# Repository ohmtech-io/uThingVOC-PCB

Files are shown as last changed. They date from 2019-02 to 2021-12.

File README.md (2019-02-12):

# uThing::VOC Hardware
### Air-Quality sensor USB dongle with configurable output format

#### Schematic and PCB manufacturing files for the uThing::VOC

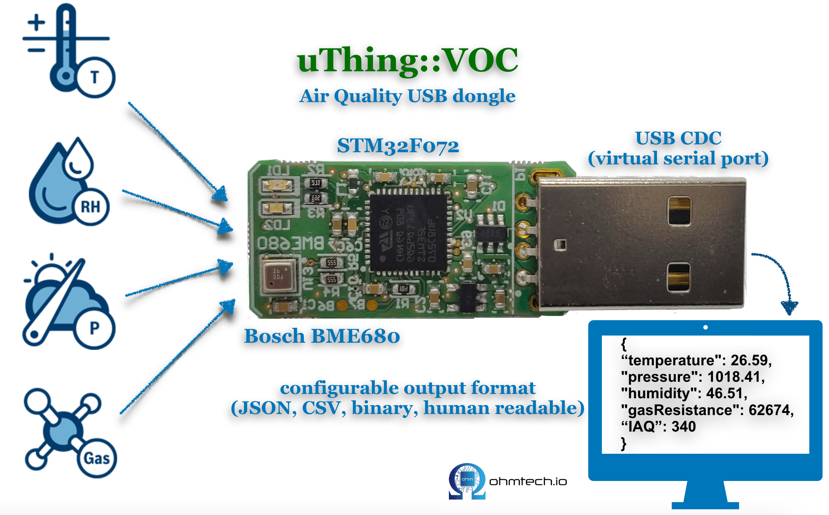
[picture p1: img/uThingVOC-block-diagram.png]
uThingVOC


This repository contains the design files for the revision.1 of the OhmTech's uThing::VOC USB dongle.

The PCB is layered out in a 4-layer FR4 board.

Below is a list of the requirements for the fabrication technology:

* Number of Layers: 4
* Total board thickness: 1.55 mm
* Legend (silkscreen): White. Top and Bottom
* Base material: FR4
* Smallest via: >= 0.25 mm
* Outer layer isolation distance ﴾OL‐TT‐TP‐PP: 0.150 mm (6 mil)
* Outer layer track-width ﴾IL‐TW﴿: 0.150 mm (6 mil)
* Inner layer isolation distance ﴾IL‐TT‐TP‐PP: 0.150 mm (6 mil)
* Inner layer track-width ﴾IL‐TW﴿: 0.150 mm (6 mil)
* Board buildup: Standard, no special requirement
* Inner layer copper foil: 35 um
* Outer layer copper foil: 18 um
* Surface finish: any lead-free finish

The PCB Outer dimensions are 30x14.5 mm, with the USB-A connector installed the final dimension is approx. 48x15x5 mm.

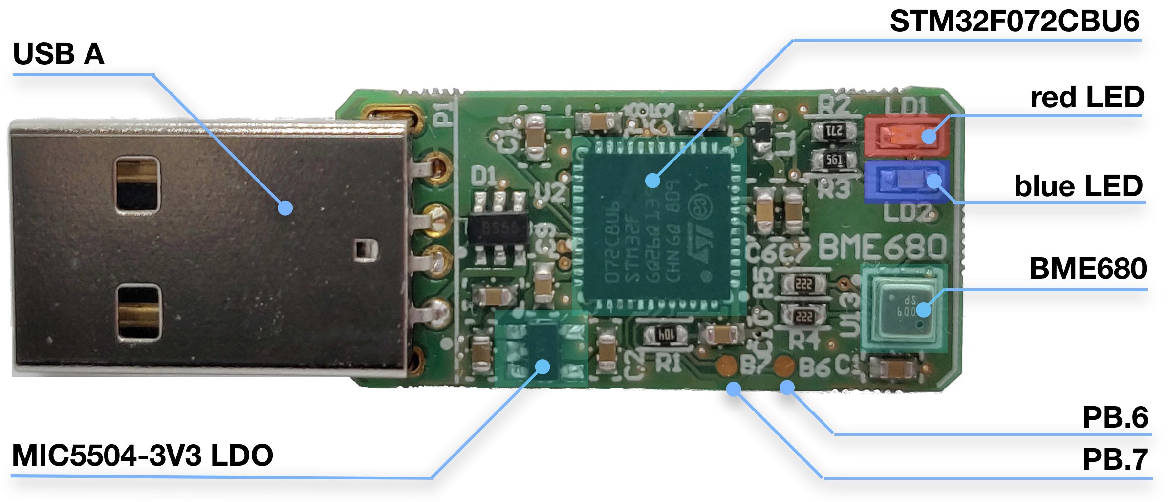
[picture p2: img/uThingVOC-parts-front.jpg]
uThingVOCfront

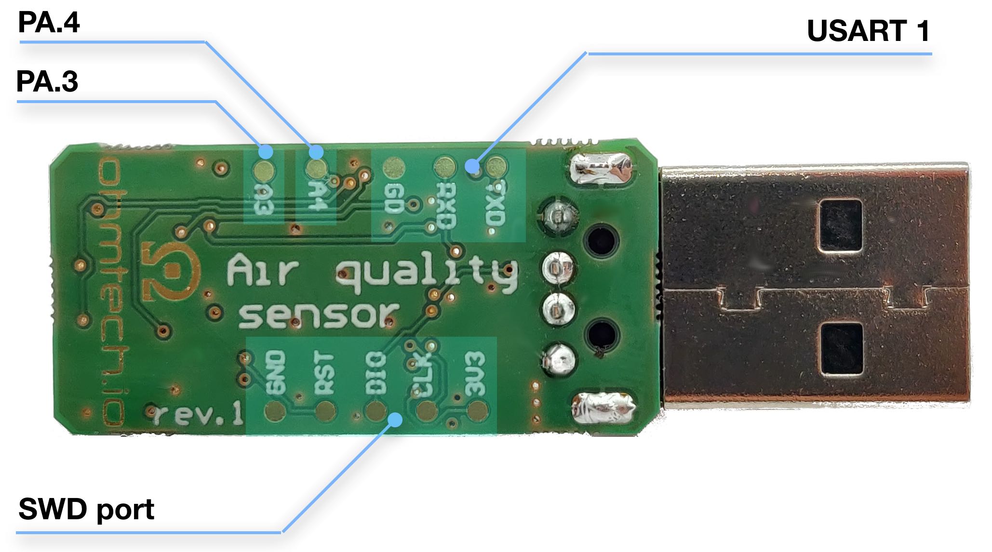
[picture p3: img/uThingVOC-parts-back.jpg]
uThingVOCback


Gerber BOM and Pick&Place files are provided for PCB manufacturing and assembly.

* The Firmware source code can be found here: https://github.com/ohmtech-io/uThingVOC.git
* The assembled boards can be obtained at the Tindie store: https://www.tindie.com/products/damancuso/uthingvoc/

If you like the project please share and follow us on [Tweeter](https://twitter.com/OhmTechIot) :)

------------------

**License**

**Copyright (c) 2019 Daniel Mancuso - OhmTech.io**

<br />This work is licensed under a <a rel="license" href="http://creativecommons.org/licenses/by-sa/4.0/">Creative Commons Attribution-ShareAlike 4.0 International License</a>.

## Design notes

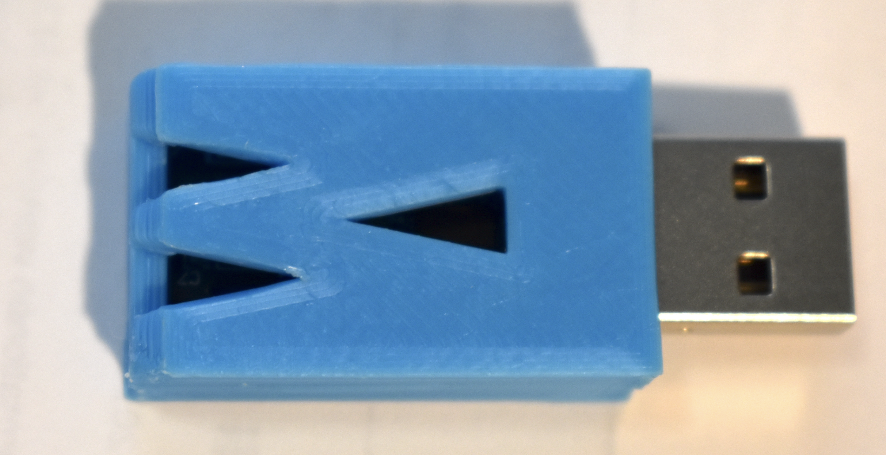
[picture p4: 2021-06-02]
VOC_revB-enclosure-PLA-blue.png

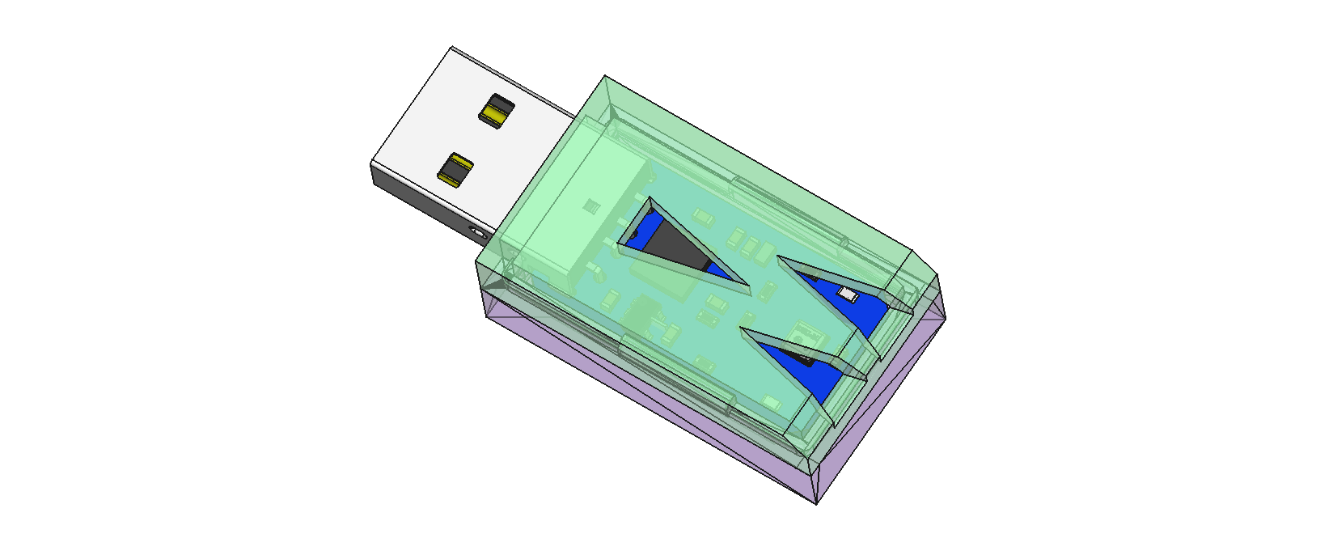
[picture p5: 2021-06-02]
Enclosure3Dmodel/EnclosureRev2-3Dmodel.png

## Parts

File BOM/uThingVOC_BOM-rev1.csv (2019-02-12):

Designator | Value | Comment | Description | Footprint | LibRef | Manufacturer 1 | Manufacturer Part Number 1 | Quantity | Supplier 1 | Supplier Part Number 1
C1, C3, C8, C9, C10 | 100n | Cap0603 | -55-125C, 1608, 10V, X7R, ±10% | CAP 0603/1608 | CAP_0603 | Samsung Electro-Mechanics | CL10B104KO8NNNC | 5 | Digi-Key | 1276-1005-1-ND
C2, C4, C7 | 1u | X7R | -55-125C, 1608, 10V, X7R, ±10% | CAP 0603/1608 | CAP_0603 | Samsung Electro-Mechanics | CL10B105MO8NNWC | 3 | Digi-Key | 1276-6524-1-ND
C5, C6 | 10n | Cap0603 | -55-125C, 1608, 10V, X7R, ±10% | CAP 0603/1608 | CAP_0603 | Samsung Electro-Mechanics | CL10B103KB8NCNC | 2 | Digi-Key | 1276-1921-1-ND
C11 | 4.7u | Cap0603 | 4.7u 0603 | CAP 0603/1608 | CAP_0603 | Samsung Electro-Mechanics | CL10A475MP5LNNC | 1 | Digi-Key | 1276-6684-1-ND
D1 |  | ESDA6V1BC6 | 4-line ESD protection | SOT23-6L | ESDA6V1BC6 | STMicroelectronics | ESDA6V1BC6 | 1 | Digi-Key | 497-6635-1-ND
L1 |  | Ferrite | Ferrite Bead, 0603,1.5Kohm@100MHz, 300mA-max | IND0603 | MMZ1608Y152BTD25 | TDK Corporation | MMZ1608Y152BTD25 | 1 | Digi-Key | 445-172846-1-ND
LD1 |  | Red | Typical RED, GREEN, YELLOW, AMBER GaAs LED | LED0603 | LED_RED | Lite-On Inc. | LTST-C191KRKT | 1 | Digi-Key | 160-1447-1-ND
LD2 |  | Blue | Blue LED 0604 | LED0603 | LED_BLUE | Everlight Electronics Co Ltd | EAST16084BA8 | 1 | Digi-Key | 1080-1562-1-ND
P1 |  | USB-A-Plug | Conn USB RCP 4 POS 2.5mm Solder RA Edge Mount 4 Terminal 1 Port | USB-A-plug | USB-A-Plug | CUI Inc. | UP2-AH-1-TH | 1 | Digi-Key | 102-3996-ND
R1 | 100K | Res0603, 0.1W | 0.10W, -55-155C, 1005, 50V, ±1% | RES 0603/1608 | RES_0603 | Stackpole Electronics Inc. | RMCF0603JG100K | 1 | Digi-Key | RMCF0603JG100KCT-ND
R2 | 270R | Res0603, 0.1W | 0.10W, -55-155C, 1005, 50V, ±1% | RES 0603/1608 | RES_0603 | Stackpole Electronics Inc. | RMCF0603JT270R | 1 | Digi-Key | RMCF0603JT270RCT-ND
R3 | 560R | Res0603, 0.1W | 0.10W, -55-155C, 1005, 50V, ±1% | RES 0603/1608 | RES_0603 | Stackpole Electronics Inc. | RMCF0603JT560R | 1 | Digi-Key | RMCF0603JT560RCT-ND
R4, R5 | 2K2 | Res0603, 0.1W | 0.10W, -55-155C, 1005, 50V, ±1% | RES 0603/1608 | RES_0603 | Stackpole Electronics Inc. | RMCF0603JT2K20 | 2 | Digi-Key | RMCF0603JT2K20CT-ND
U1 |  | MIC5504-3V3 | Linear Voltage Regulator IC Positive Fixed 1 Output 3.3V 300mA SOT-23-5 | SOT-23-5 | MIC5504-3V3 | Microchip Technology | MIC5504-3.3YM5-TR | 1 | Digi-Key | 576-4764-1-ND
U2 |  | STM32F072CBU6 | ARM-based 32-bit MCU with 128KB Flash / 8KB ram, USB | UFQFPN48-2 | STM32F072CBU6 | STMicroelectronics | STM32F072CBU6 | 1 | Digi-Key | 497-14646-ND
U13 |  | BME680 | Bosch Sensortec VOC, Temp, Hum and barometric sensor | BME680 | BME680 | Bosch Sensortec | BME680 | 1 | Digi-Key | 828-1077-6-ND

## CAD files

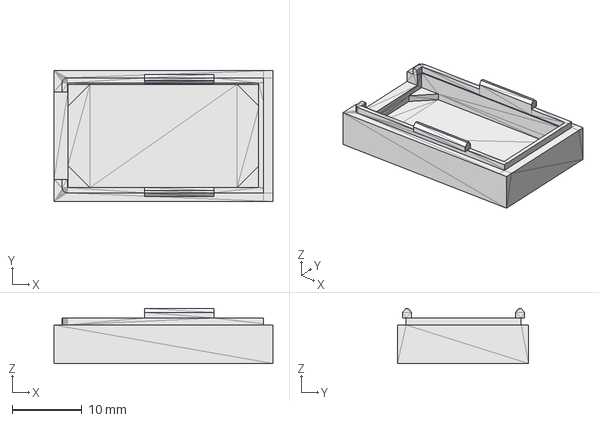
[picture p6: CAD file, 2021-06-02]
Enclosure3Dmodel/uThingVOC_REV_B_v8.FCStd
31.5 x 18.9 x 7.92 mm

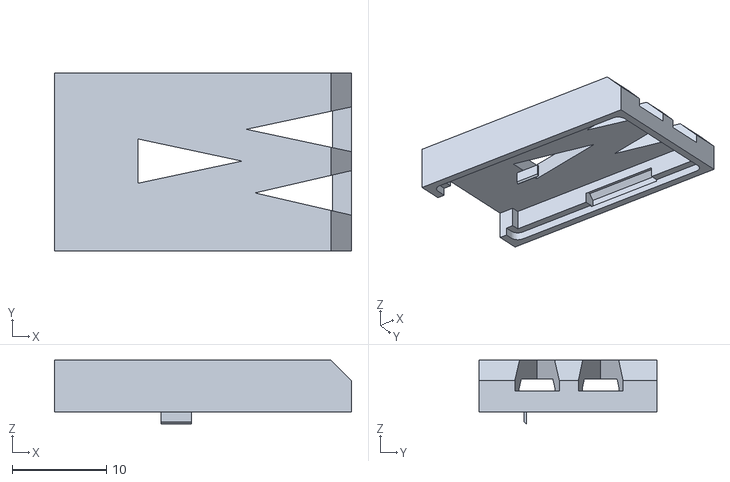
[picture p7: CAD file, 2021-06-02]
Enclosure3Dmodel/uThingVOC__REV_B_TOP_v8.stl
31.5 x 18.9 x 6.75

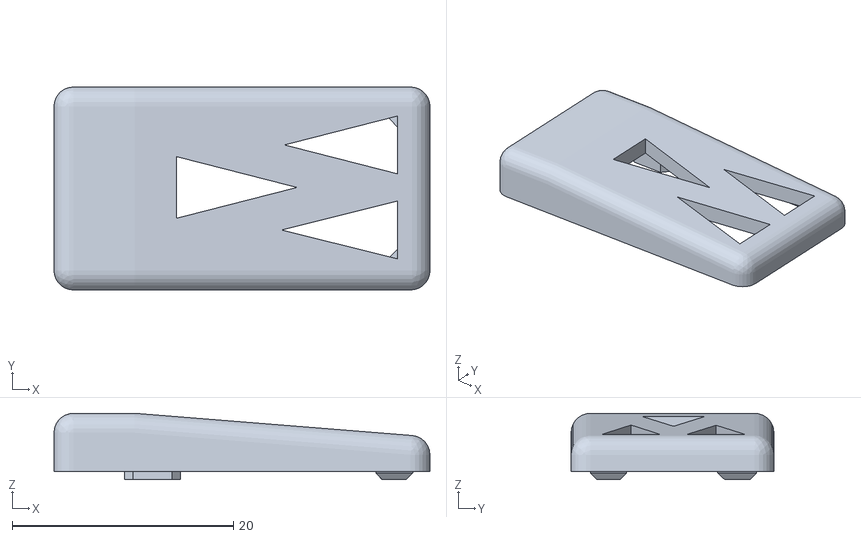
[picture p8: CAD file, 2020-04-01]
Enclosure3Dmodel/uThing_Top_v5.stl
34.0 x 18.4 x 6.00

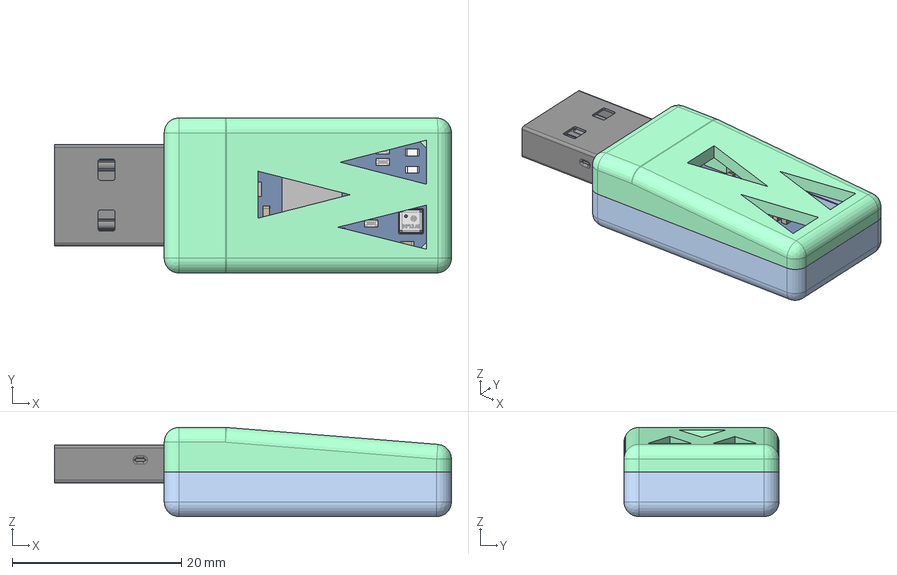
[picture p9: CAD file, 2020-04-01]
Enclosure3Dmodel/uThing_v5.FCStd
47.0 x 18.4 x 10.6 mm
0603_cap
0603_cap001
0603_cap002
0603_cap003
0603_cap004
0603_cap005
0603_cap006
0603_cap007
0603_cap008
0603_cap009
0603_cap010
Extruded
Extruded001
Extruded002
Extruded003
Extruded004
Extruded005
Extruded006
Extruded007
CUI_UP2-AH-1-TH
0603_resistor
0603_resistor001
0603_resistor002
0603_resistor003
0603_resistor004
SOT-23-5
Extruded008
User_Library-BME680_Part_2896
User_Library-BME680_Part_881
User_Library-BME680_Part_910
User_Library-BME680_Part_970
User_Library-BME680_Part_1035
User_Library-BME680_Part_1159
User_Library-BME680_Part_1187
User_Library-BME680_Part_1282
User_Library-BME680_Part_2249
User_Library-BME680_Part_2895
User_Library-BME680_Part_547
User_Library-BME680_Part_546
BottomLid
TopLid

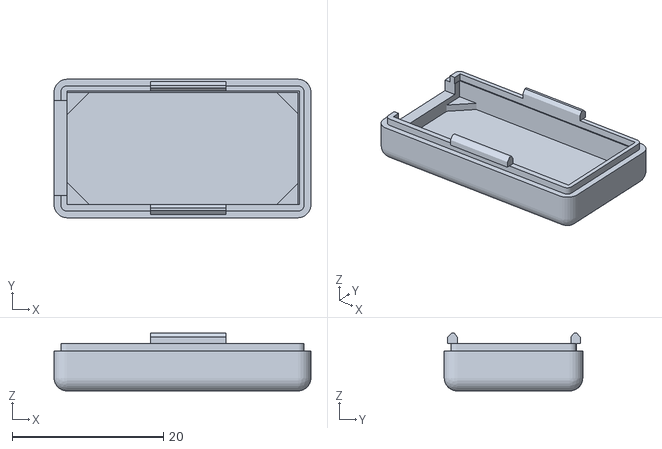
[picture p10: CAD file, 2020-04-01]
Enclosure3Dmodel/uThing_Bottom_v5.stl
34.0 x 18.4 x 7.67

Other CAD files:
Enclosure3Dmodel/uThingVOC_REV_B_Bottom_v8.stl

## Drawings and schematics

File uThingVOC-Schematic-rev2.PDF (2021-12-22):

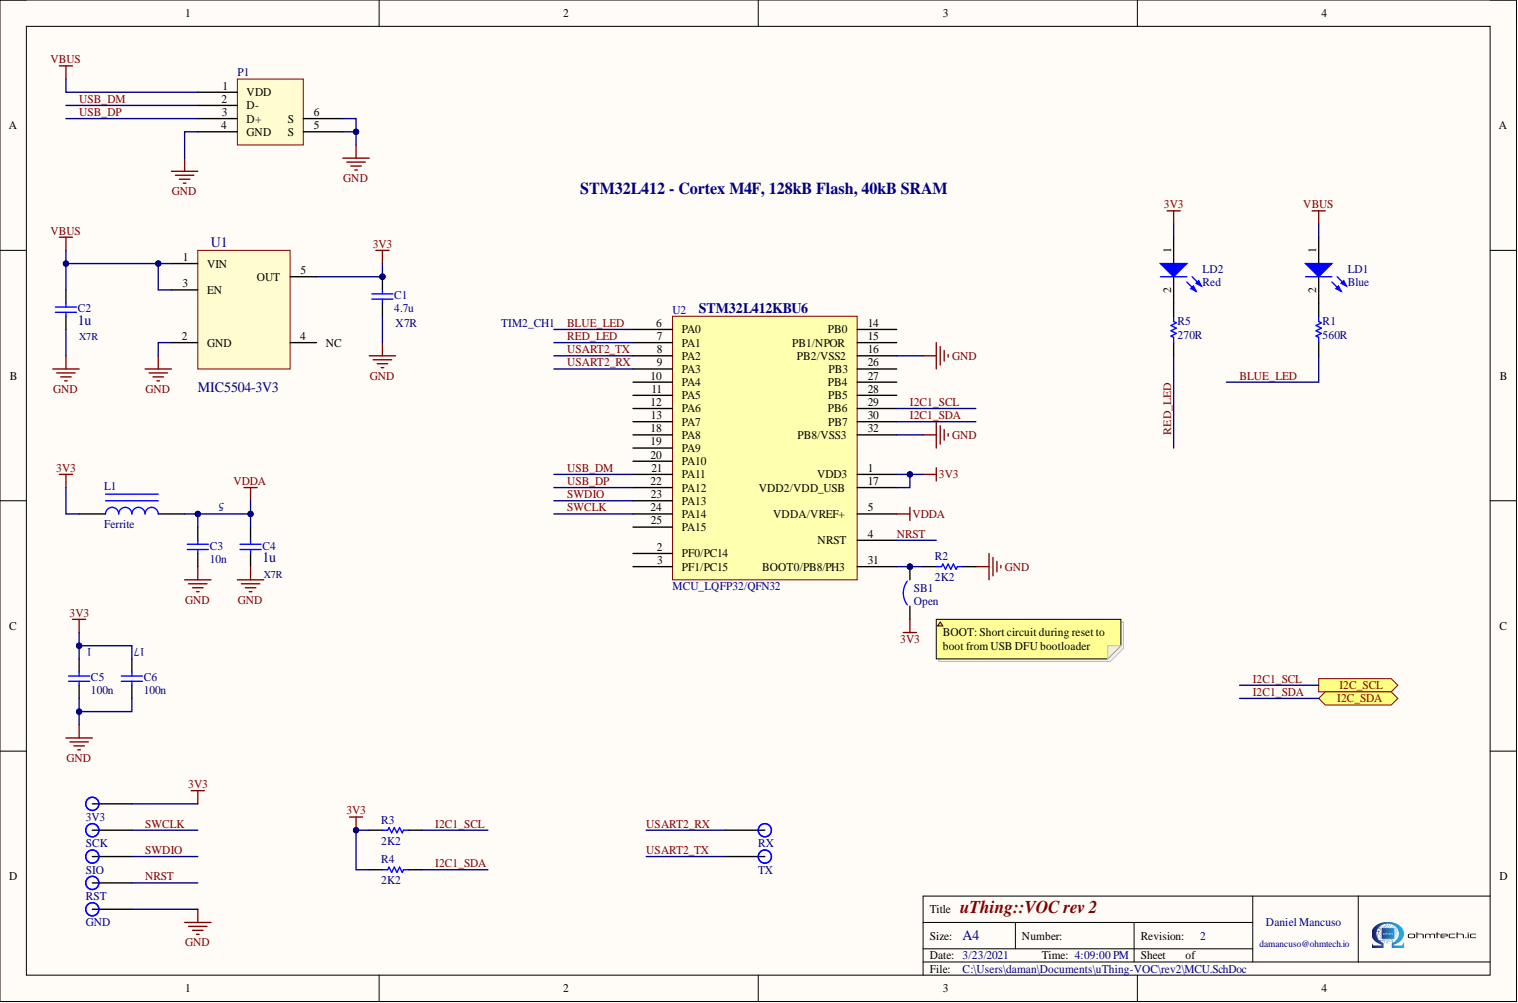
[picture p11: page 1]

BOOT: Short circuit during reset to
boot from USB DFU bootloader

uThing::VOC rev 2
Title
C:\Users\daman\Documents\uThing-VOC\rev2\MCU.SchDoc

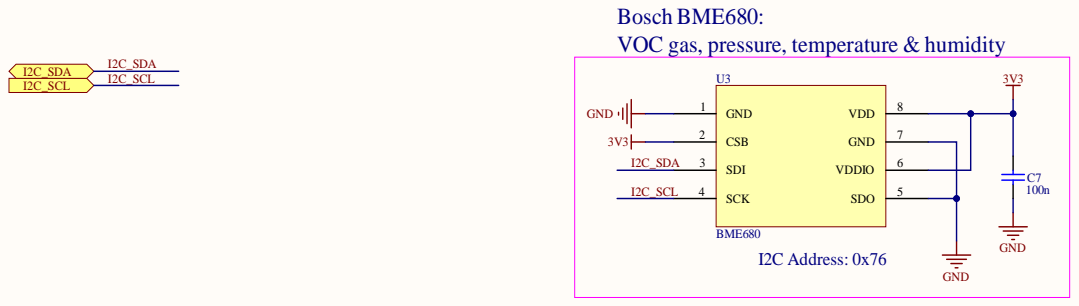
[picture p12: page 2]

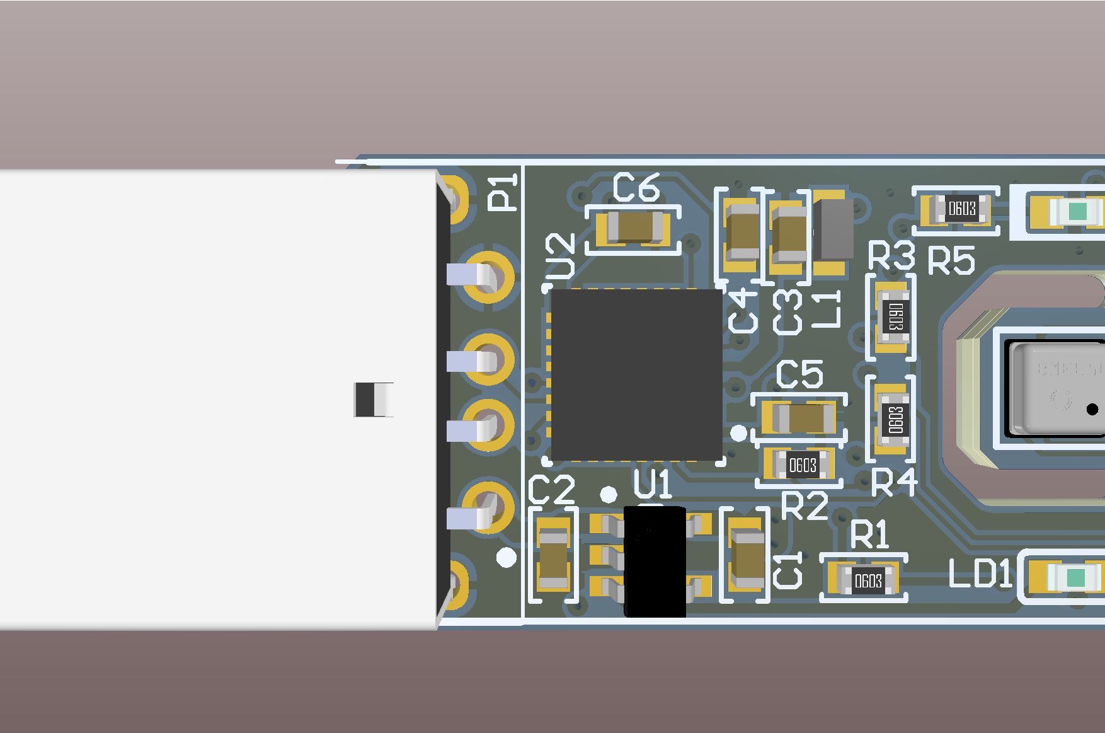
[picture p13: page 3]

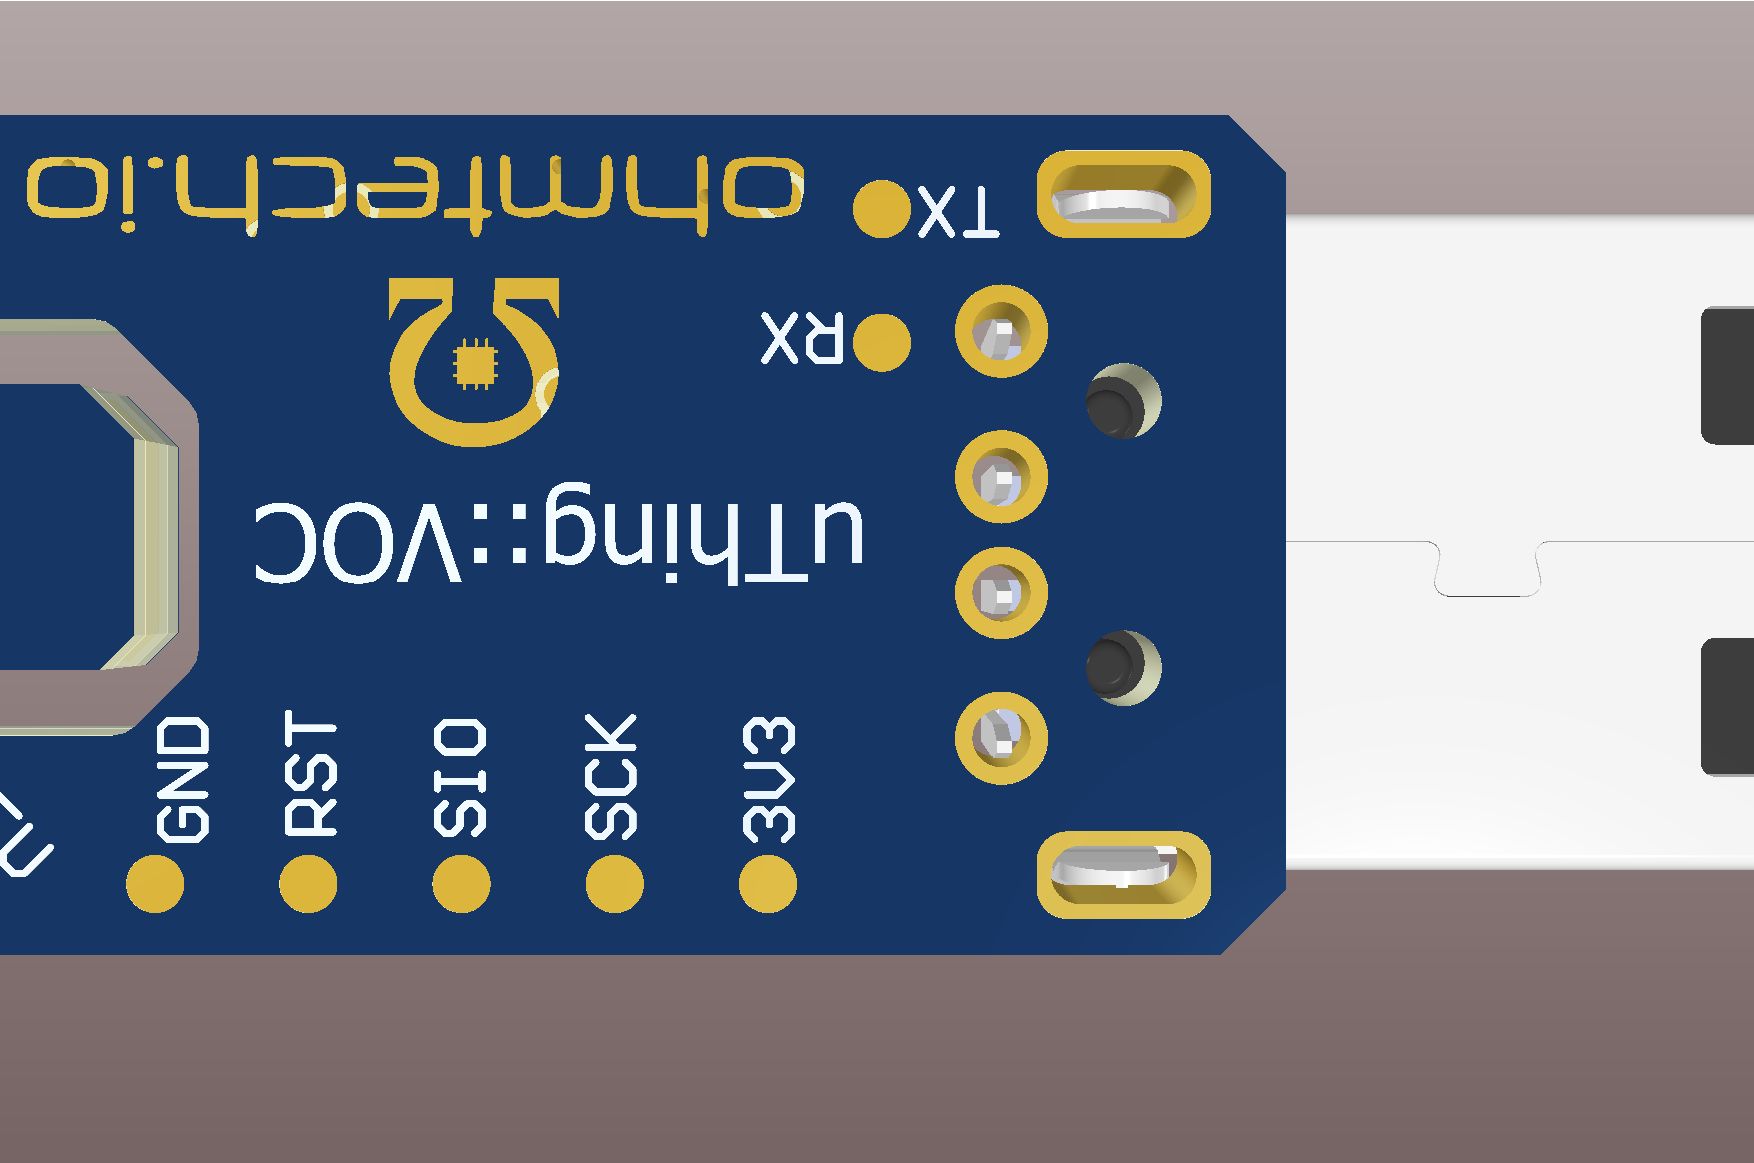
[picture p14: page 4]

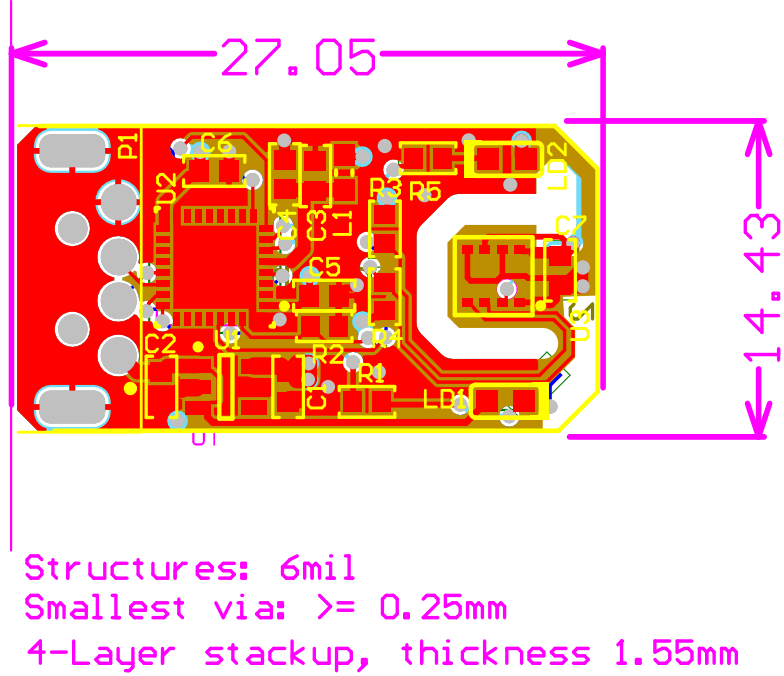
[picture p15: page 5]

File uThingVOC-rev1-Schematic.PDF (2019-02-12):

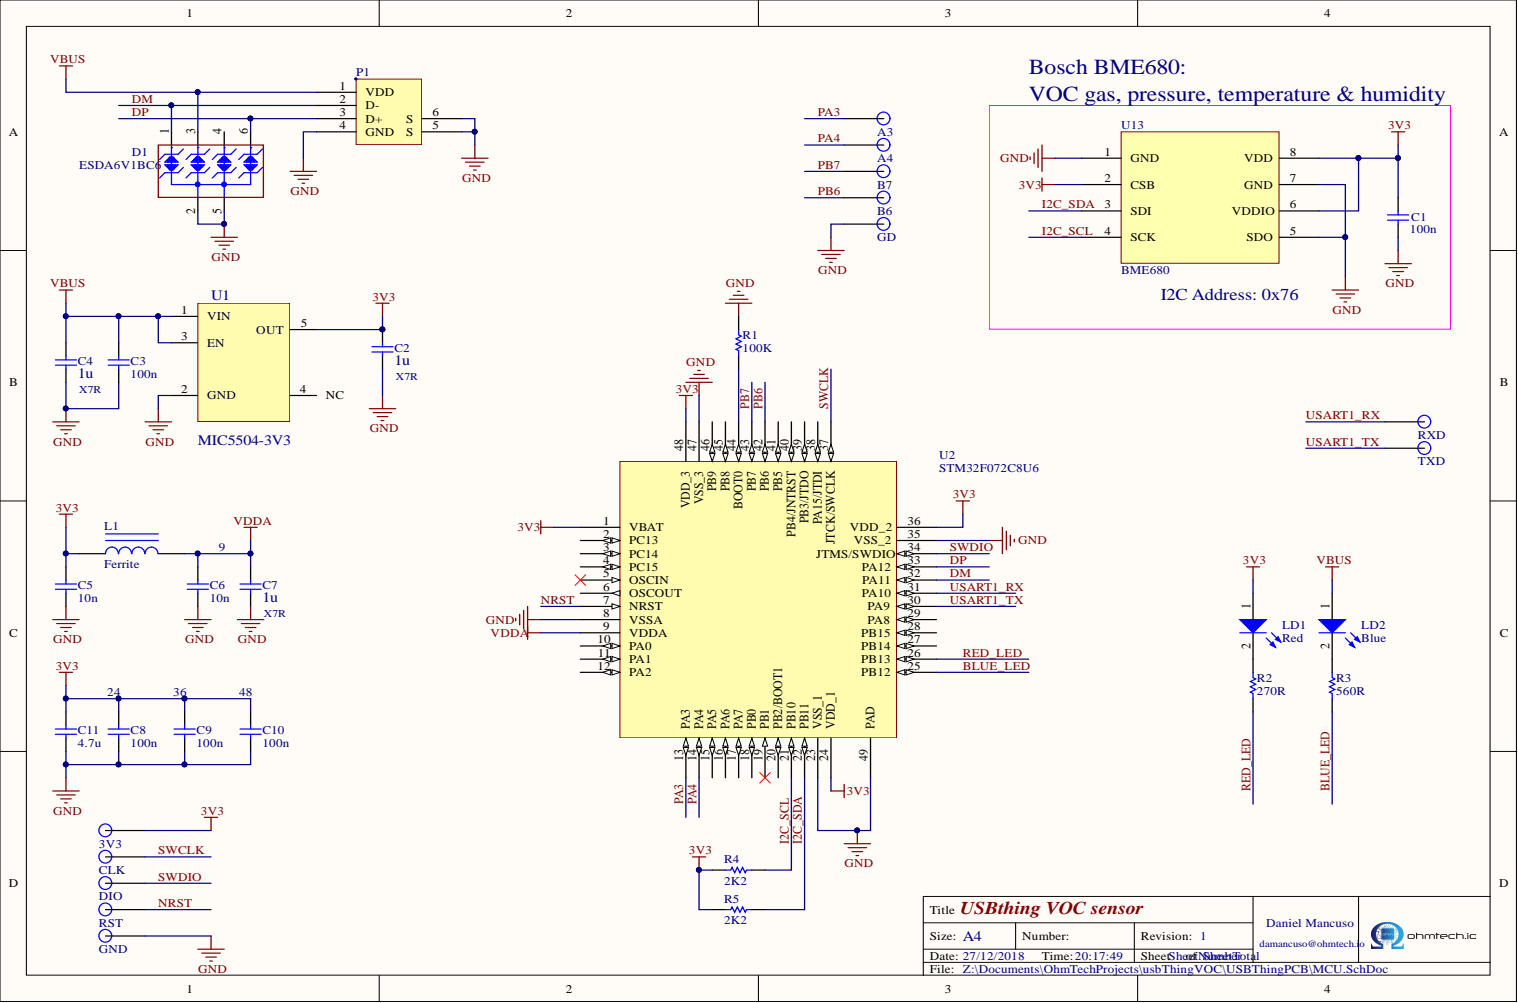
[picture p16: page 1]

Bosch BME680:
VOC gas, pressure, temperature & humidity

USBthing VOC sensor Title | Daniel Mancuso damancuso@ohmtech.io
A4 Size: | Number: | Revision: 1

Date: 27/12/2018 Time: 20:17:49 | | Sheet SheetNShumbeeterTotal of

Z:\Documents\OhmTechProjects\usbThingVOC\USBThingPCB\MCU.SchDoc

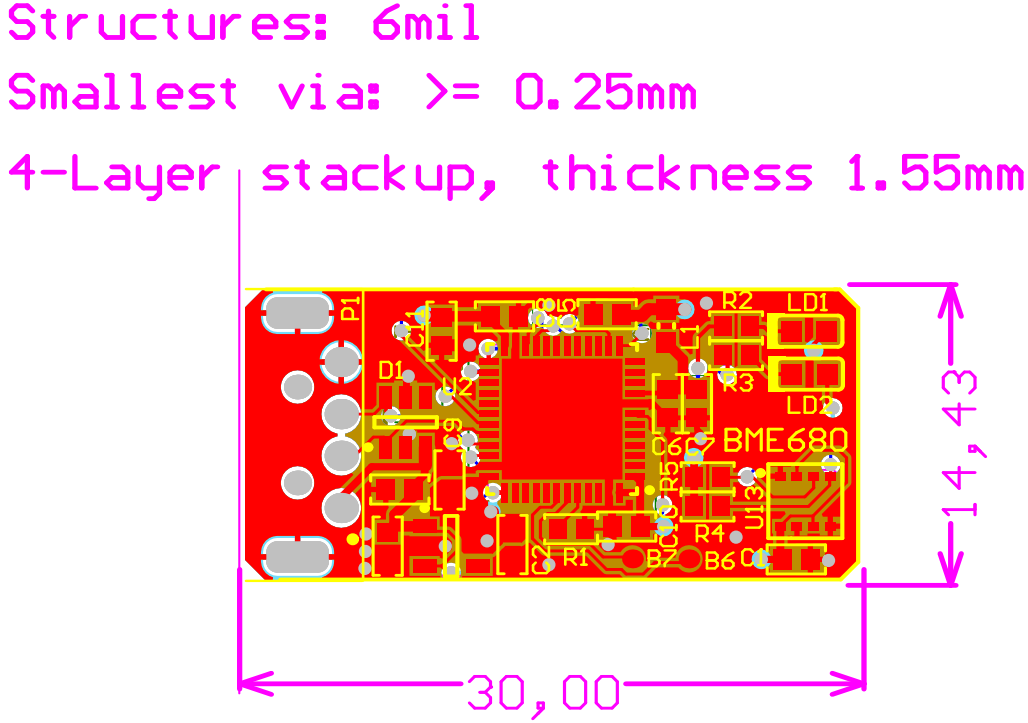
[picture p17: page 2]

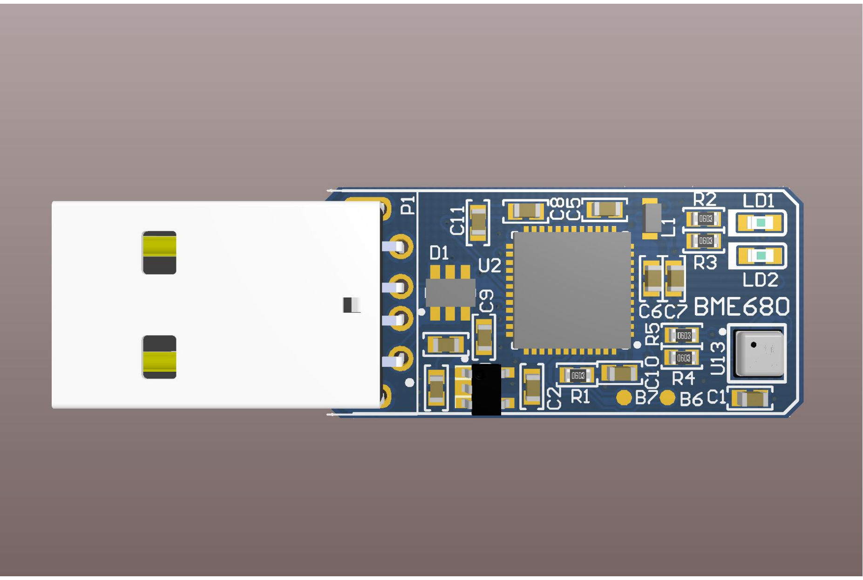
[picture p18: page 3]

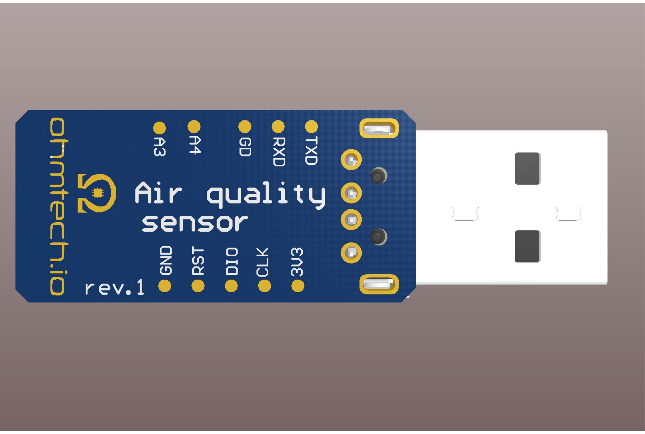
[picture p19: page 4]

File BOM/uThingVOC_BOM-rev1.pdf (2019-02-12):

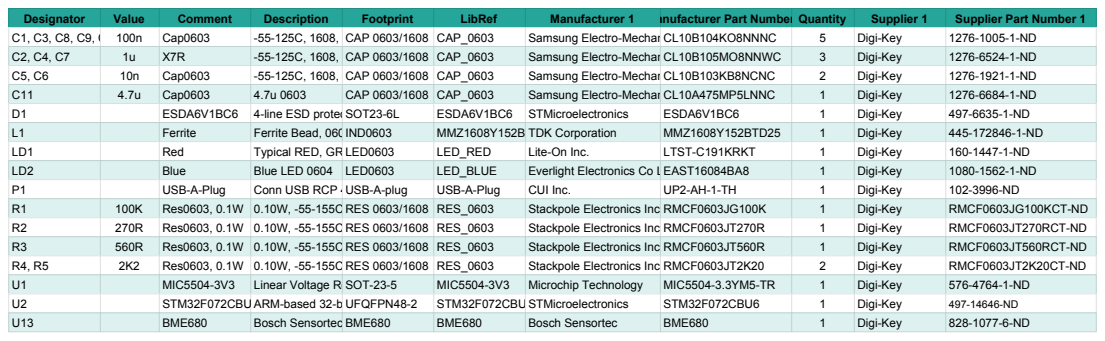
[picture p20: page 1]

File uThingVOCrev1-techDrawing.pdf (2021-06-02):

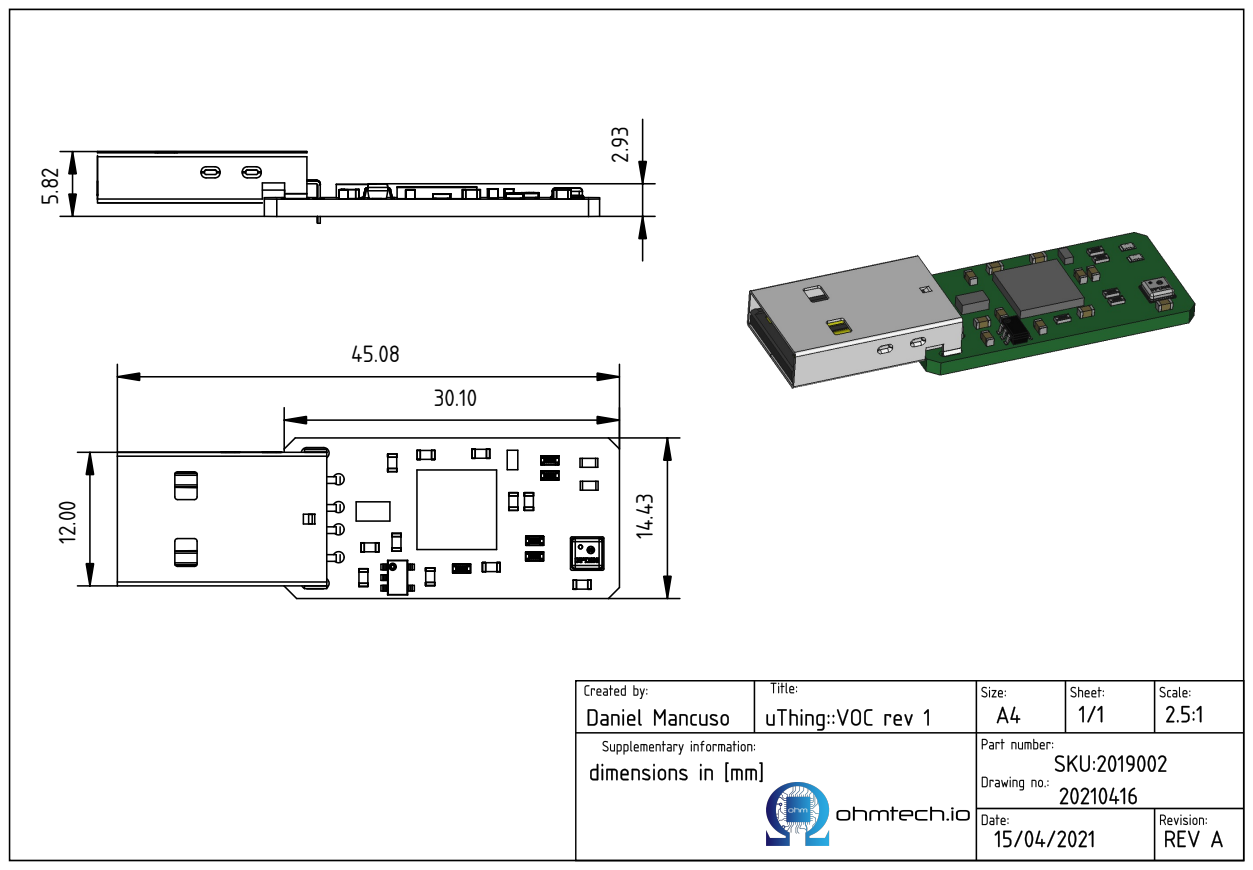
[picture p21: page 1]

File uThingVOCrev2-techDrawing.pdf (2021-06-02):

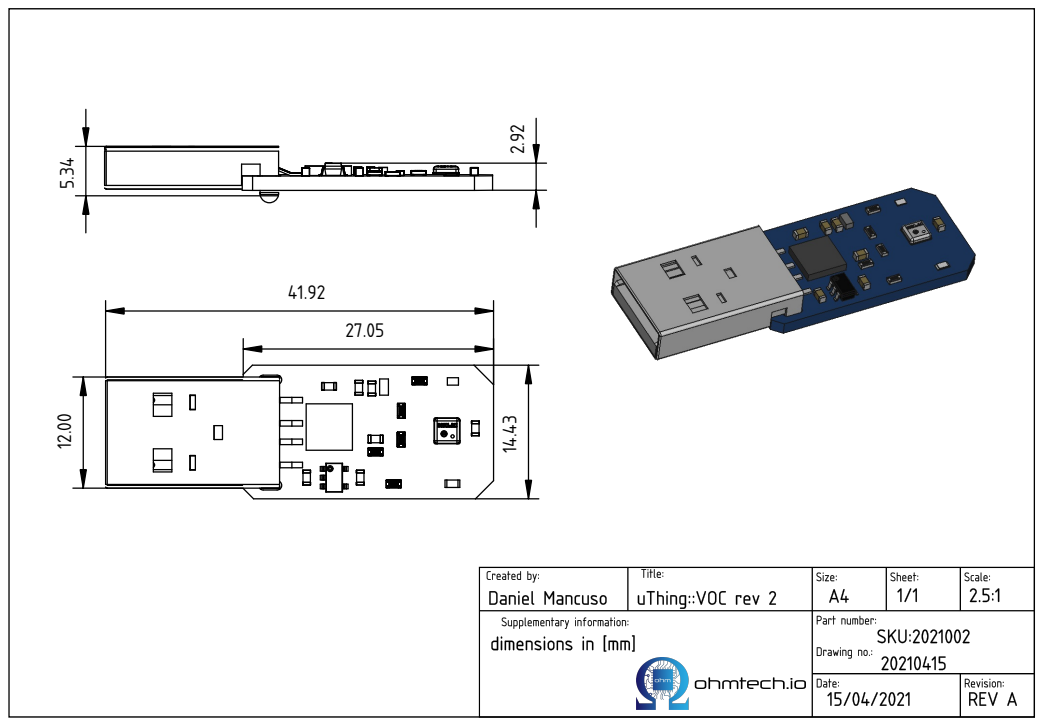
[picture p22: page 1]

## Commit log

2019-02-12 adding manufacturing files and Readme
    [USBThingPCB.GBL, USBThingPCB.GBO, USBThingPCB.GBP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]
2020-04-01 Add files via upload
    add STL and FreeCAD source of the enclosure
    [uThing_Bottom_v5.stl, uThing_Top_v5.stl, uThing_v5.FCStd]
2021-06-02 adding 3D model and FreeCAD source for PCB Revision B
    [uThingVOC_REV_B_Bottom_v8.stl, uThingVOC_REV_B_v8.FCStd, uThingVOC__REV_B_TOP_v8.stl]
2021-06-02 add render of the Enclosure for Rev B
2021-06-02 add picture of 3D printed enclosure
2021-06-02 add picture of 2D printed enclosure
2021-12-22 add schematics for revision 2
